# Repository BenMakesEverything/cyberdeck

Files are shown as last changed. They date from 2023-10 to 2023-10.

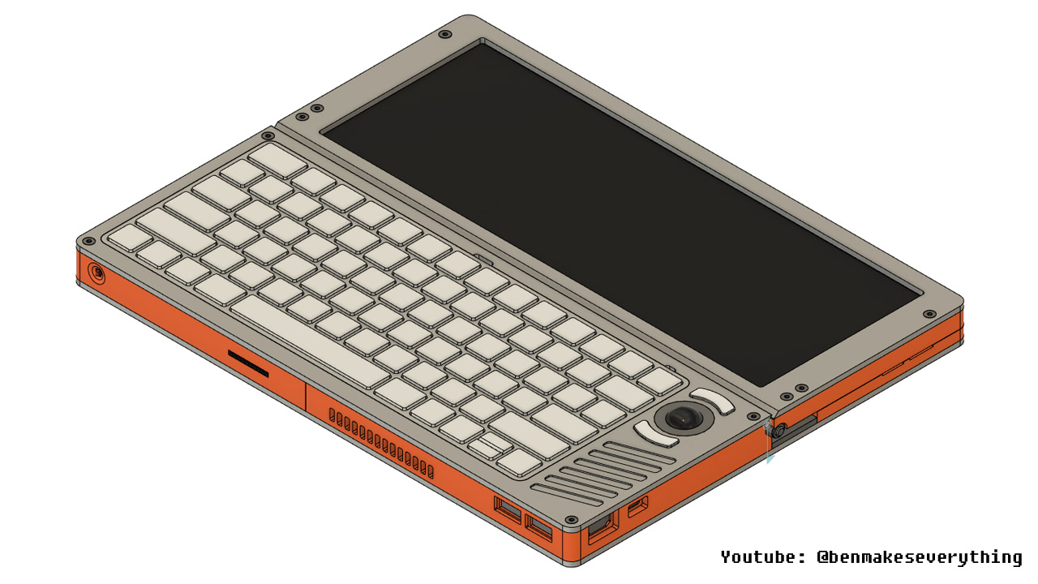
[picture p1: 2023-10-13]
cyberdeck-preview-1280x720.jpg

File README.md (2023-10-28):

# Framework Cyberdeck
cyberdeck-preview-1280x720

### This is a custom built portable PC using Framework components.

## 3D Files:

Full project file: cyberdeck-final.zip (step format) or cyberdeck-final.f3z (fusion 360)

If you only want the 3D printed parts: download cyberdeck-print-files-only.zip (step format)

If you only want the flat top/bottom plates: download cyberdeck-plates-only.zip (step format)

## STL Files:

The 3D printed frame has been broken up into 4 parts and the screen frame into 2 parts to fit standard-sized printers.

You need:

frame-top-left, frame-top-right, frame-bottom-left, frame-bottom-right, screen-frame-left, screen-frame-right, and button (printed x2)

I printed mine at 50% infill for strength and durability.

For the plates, I reccommend using something other than PLA, plus they are too big for most printers. Get it laser cut from acrylic or machined from aluminum. For that purpose I have included 2D versions of the files, if you want to use a laser. Otherwise just use the regular ones that have the bevels and other features.

## Code:

Trackball Arduino code: trackball.ino

## Parts List:

Motherboard/CPU, Expansion Cards, Battery, Speakers, Wifi Card: https://frame.work/marketplace

RAM: https://www.newegg.com/corsair-16gb-260-pin-ddr4-so-dimm/p/N82E16820236663

SSD: https://www.newegg.com/western-digital-500gb-sn770/p/N82E16820250216

Antenna: https://www.amazon.com/gp/product/B07DB5VWS1/

Keyboard: https://www.ebay.com/ - Search “Magic Keyboard 2”

Keyboard cable: https://smarthomemount.com/products/slim-power-cable-male-usb-a-to-90-degree-apple-lightning

Screen: https://www.amazon.com/gp/product/B0BZYXFSCX/

Screen Cable (USB C, 1 right angle end): https://www.amazon.com/gp/product/B0BZPSPFV1

L shape USB Connector: https://www.amazon.com/gp/product/B0BCGH47CN/

USB C to mini cable: https://www.amazon.com/gp/product/B0744BKDRD/

Arduino Pro Micro: https://www.amazon.com/gp/product/B01MTU9GOB/

LOGITECH T-SBC12-CPQ Trackball: https://www.ebay.com/itm/372128644088

Hinges: https://www.amazon.com/gp/product/B0BNH8985Y/

USB Hub: https://www.amazon.com/gp/product/B0BLJFZ42M/

Threaded Inserts (M2): https://www.amazon.com/gp/product/B088QJG676/

Threaded Inserts (M3): https://www.amazon.com/gp/product/B08BCRZZS3/

Aluminum Plate (x2): https://www.amazon.com/gp/product/B0BFR7DSBP/

Rubber Feet: https://www.amazon.com/gp/product/B0B2KSPPHS

Power switch (I removed the metal tab): https://www.amazon.com/gp/product/B07YQQ3R7W/

Also uses various metric hardware: m2, m3 and m4 bolts.

## Hardware:

Standard Hex head bolts:

Motherboard mounting - [5] M4x8mm

Hinges (bottom part) - [4] M3x8mm

Wifi card - [1] M3x6mm

Display boards, hub - [7] M2x4mm

Tapered Head bolts (listed length includes head):

Front plates - [6] M3x6mm

Hinges (front part, goes through plate) - [4] M3x16mm, [4] M3 Nuts

Speakers - [4] M3x8mm

### Enjoy!

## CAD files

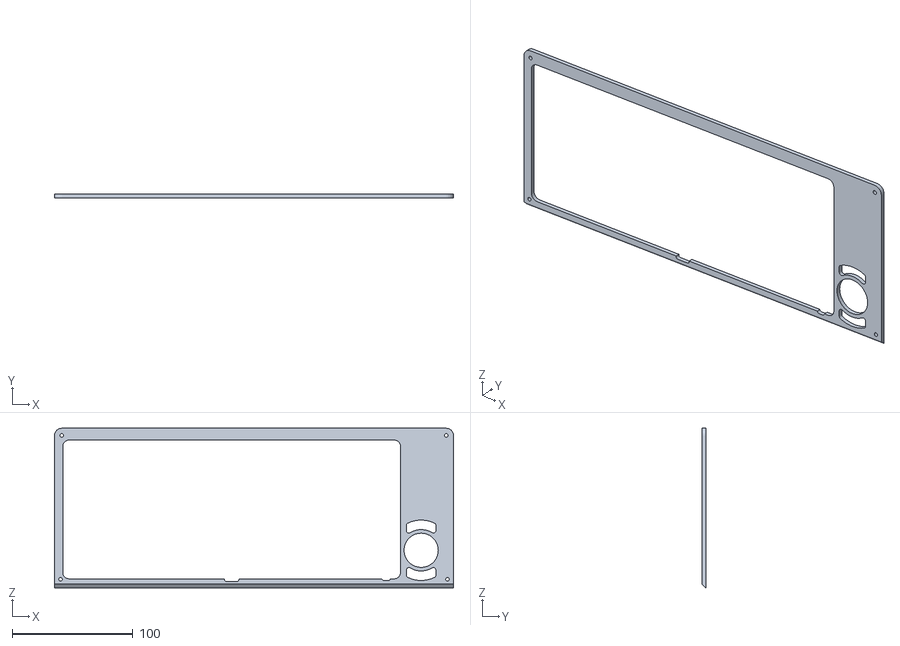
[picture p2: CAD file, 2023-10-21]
cyberdeck-keyboard-plate-2D.stl
330.0 x 3.17 x 132.0

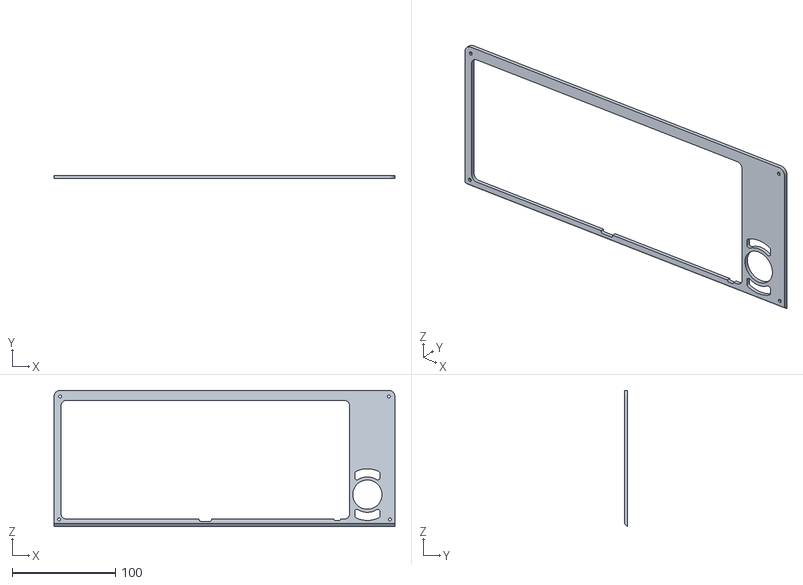
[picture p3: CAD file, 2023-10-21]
cyberdeck-keyboard-plate.stl
330.0 x 3.17 x 132.0

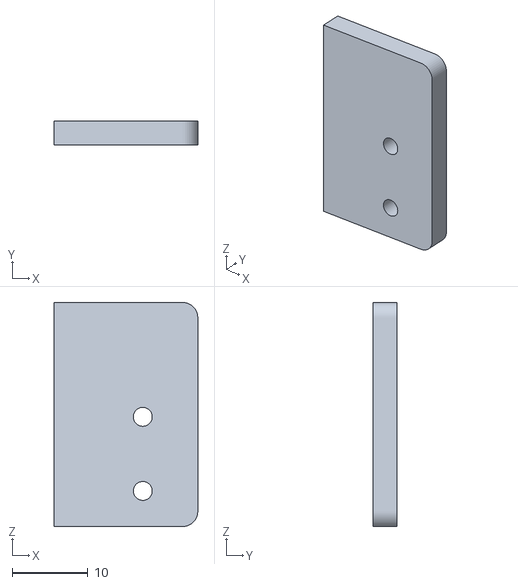
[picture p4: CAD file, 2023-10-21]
cyberdeck-hinge-support-left.stl
19.0 x 3.18 x 29.6

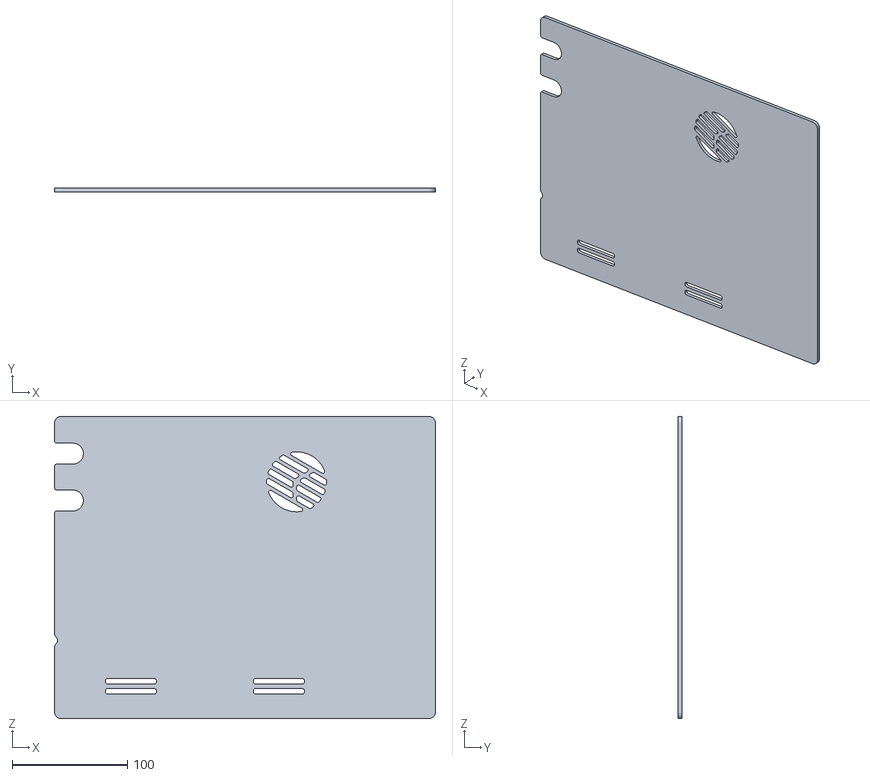
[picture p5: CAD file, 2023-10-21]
cyberdeck-baseplate.stl
330.0 x 3.17 x 262.0

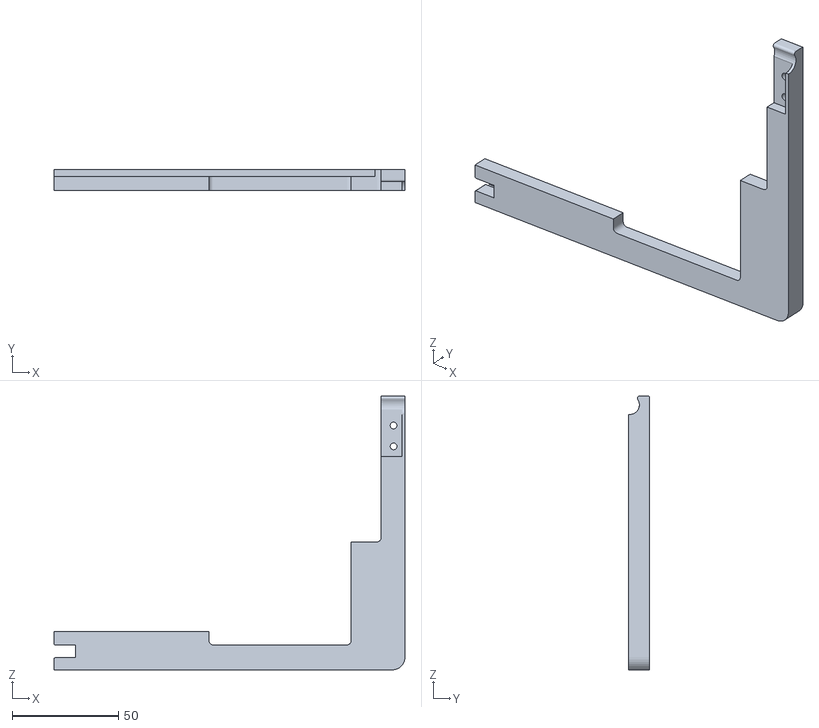
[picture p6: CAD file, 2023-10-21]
cyberdeck-screen-frame-right.stl
164.9 x 9.83 x 128.6

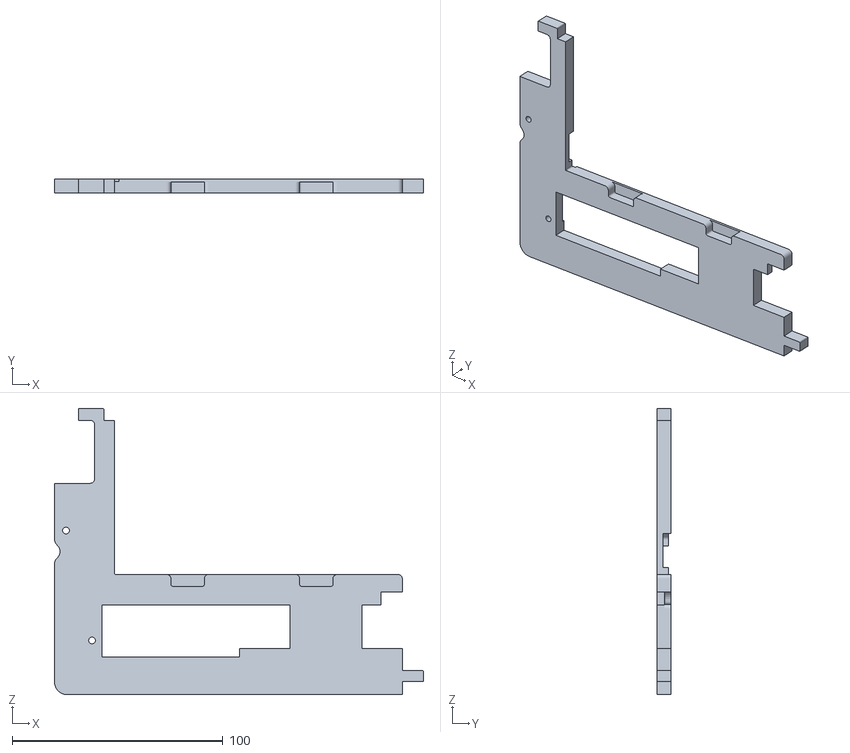
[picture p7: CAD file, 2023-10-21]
cyberdeck-frame-top-left.stl
175.0 x 6.40 x 135.7

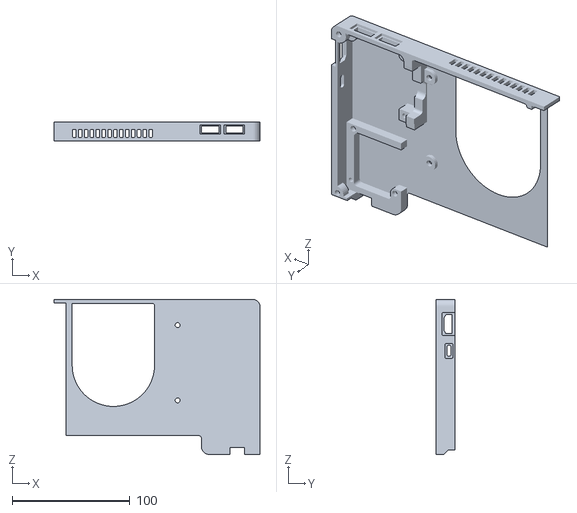
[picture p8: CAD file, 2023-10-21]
cyberdeck-frame-bottom-right.stl
175.1 x 16.4 x 131.9

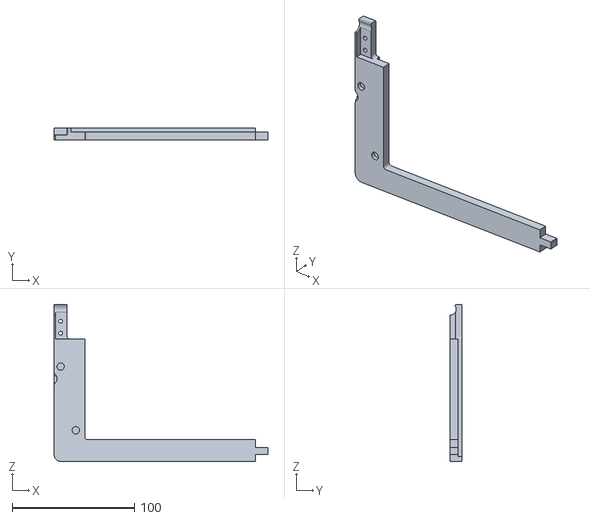
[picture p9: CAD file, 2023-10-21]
cyberdeck-screen-frame-left.stl
175.0 x 9.83 x 128.6

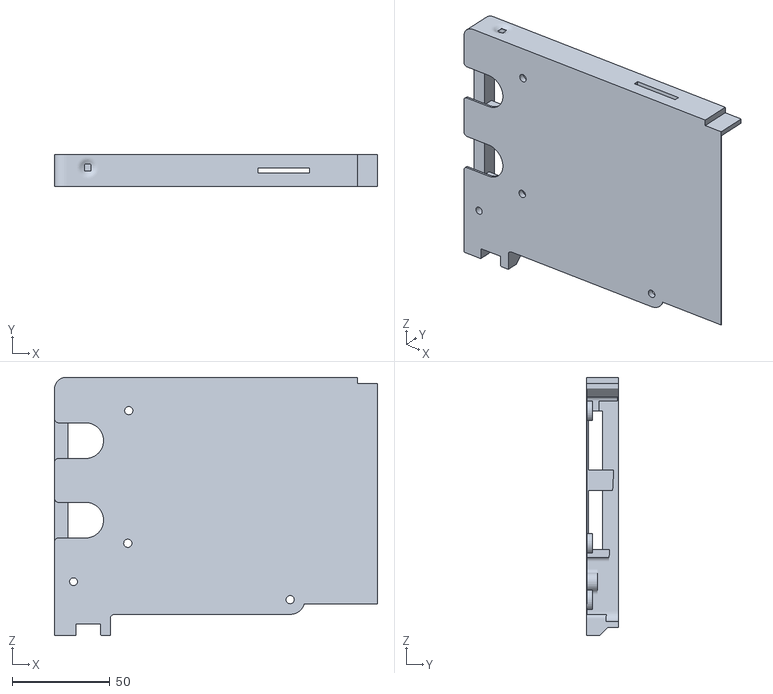
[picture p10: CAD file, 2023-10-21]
cyberdeck-frame-bottom-left.stl
164.9 x 16.4 x 131.9

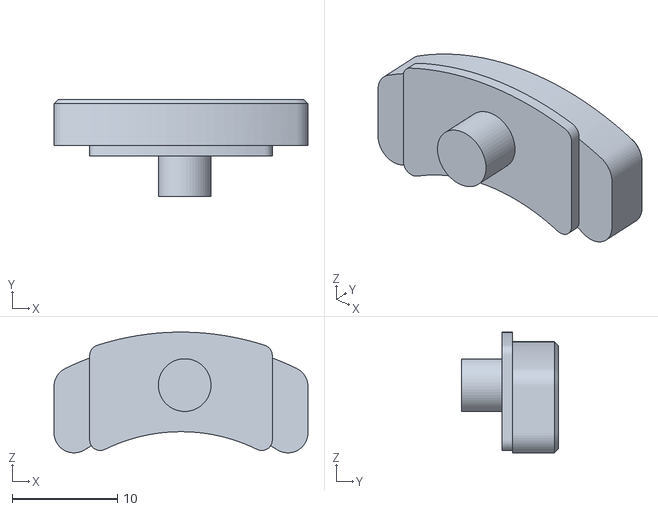
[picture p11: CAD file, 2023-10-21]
cyberdeck-button.stl
24.1 x 9.20 x 11.5

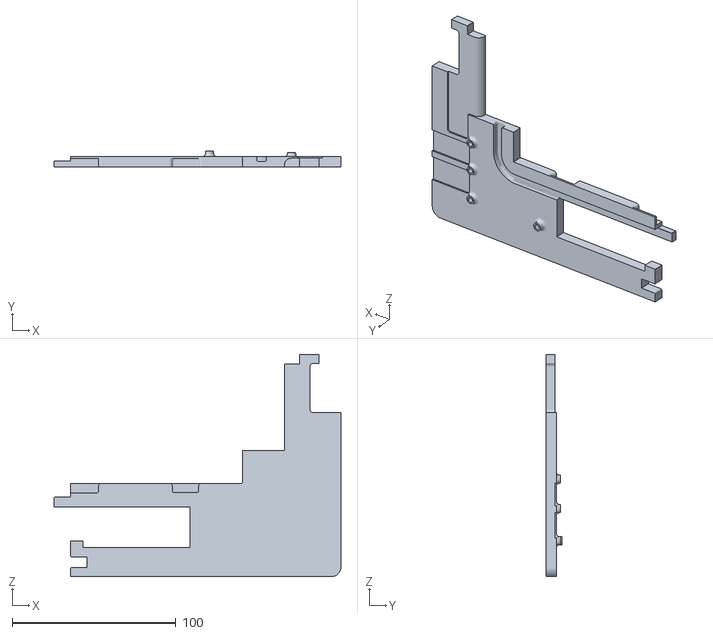
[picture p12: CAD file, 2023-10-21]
cyberdeck-frame-top-right.stl
175.1 x 9.89 x 135.7

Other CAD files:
cyberdeck-screen-plate-2D.stl
cyberdeck-screen-plate.stl
cyberdeck-hinge-support-right.stl

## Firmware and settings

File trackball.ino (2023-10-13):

#include <Mouse.h>

/**
   Reads X/Y values from a PS/2 mouse connected to an Arduino         
   using the PS2Mouse library available from
     http://github.com/kristopher/PS2-Mouse-Arduino/
   Original by Kristopher Chambers <kristopher.chambers@gmail.com>
   Updated by Jonathan Oxer <jon@oxer.com.au>
   Updated again by Ben Makes Everything - youtube.com/channel/UCKU7oz0NZLOml3dzGOjPfXg
*/
#include <PS2Mouse.h>
#include <Mouse.h>
#define MOUSE_DATA 10
#define MOUSE_CLOCK 15

PS2Mouse mouse(MOUSE_CLOCK, MOUSE_DATA, STREAM);

//Trackball Speed multiplier
const int pointerSpeed = 4;

int buttonState;
int lastButtonState = 0;
unsigned long lastDebounceTime = 0;
unsigned long debounceDelay = 200;    // debounce time setting

void setup()
{
  Serial.begin(38400);
  mouse.initialize();
  //these 2 lines keep the built in LED from coming on when the trackball moves
  pinMode(LED_BUILTIN_TX,INPUT);
  pinMode(LED_BUILTIN_RX,INPUT);
}

void loop()
{
  int16_t data[3];
  mouse.report(data);
  int reading = data[0];
  Serial.println(reading);

  if (reading != lastButtonState) {
    lastDebounceTime = millis();
  }

  if (reading != buttonState) {
    buttonState = reading;
    if (reading == 9) {
      Mouse.press(MOUSE_LEFT);
    }
    else{
      Mouse.release(MOUSE_LEFT);
    }
    if (reading == 10) {
      Mouse.press(MOUSE_RIGHT);
    }
    else{
      Mouse.release(MOUSE_RIGHT);
    }
  }
  if ((data[2] != 0) || (data[1] != 0)) { // reads trackball movement and converts to pixel movement
    Mouse.move(data[1]*pointerSpeed, -data[2]*pointerSpeed, 0); // (0,0,0)==(x,y,scroll)
  }
  lastButtonState = reading;
}
